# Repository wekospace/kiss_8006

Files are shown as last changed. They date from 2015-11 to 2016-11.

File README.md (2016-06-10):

Repository content
==================

 * datasheets

Datasheets of chips on front panel.

 * front-panel

Schematics and sniffing traces of front panel.

 * pikmm

Schematic and PCB for Raspberry Pi to Kmm front panel interface.

 * pyk8006

Python files (modules, tests, examples) to drive Kmm front panel.

Devices
=======

During development, a K8006 device have been used but this product does exist under various names :
 * KMM3010-SC-B
 * K8006
 * Media Receiver 300
 * X300T
 * KISS KMM
 * Bluewin TV-Box
 * VIP 1216

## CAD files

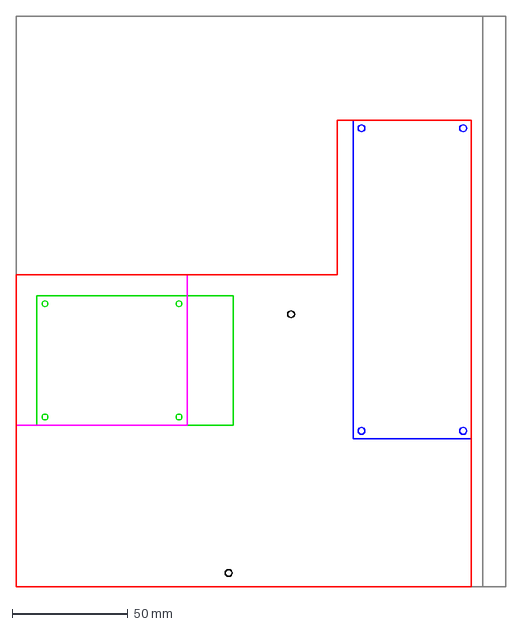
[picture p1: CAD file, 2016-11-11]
case/internal_panel_milling.dxf
212.0 x 247.0 mm

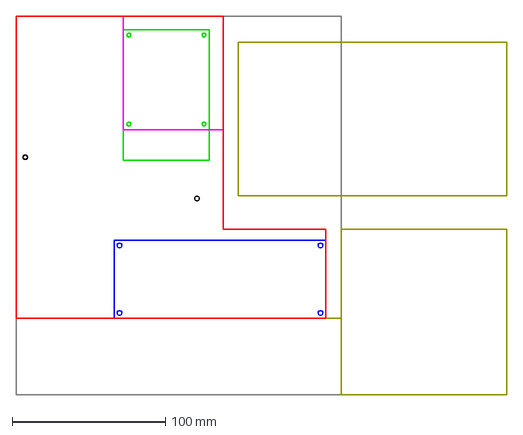
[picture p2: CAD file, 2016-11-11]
case/internal_panel.dxf
320.0 x 247.0 mm

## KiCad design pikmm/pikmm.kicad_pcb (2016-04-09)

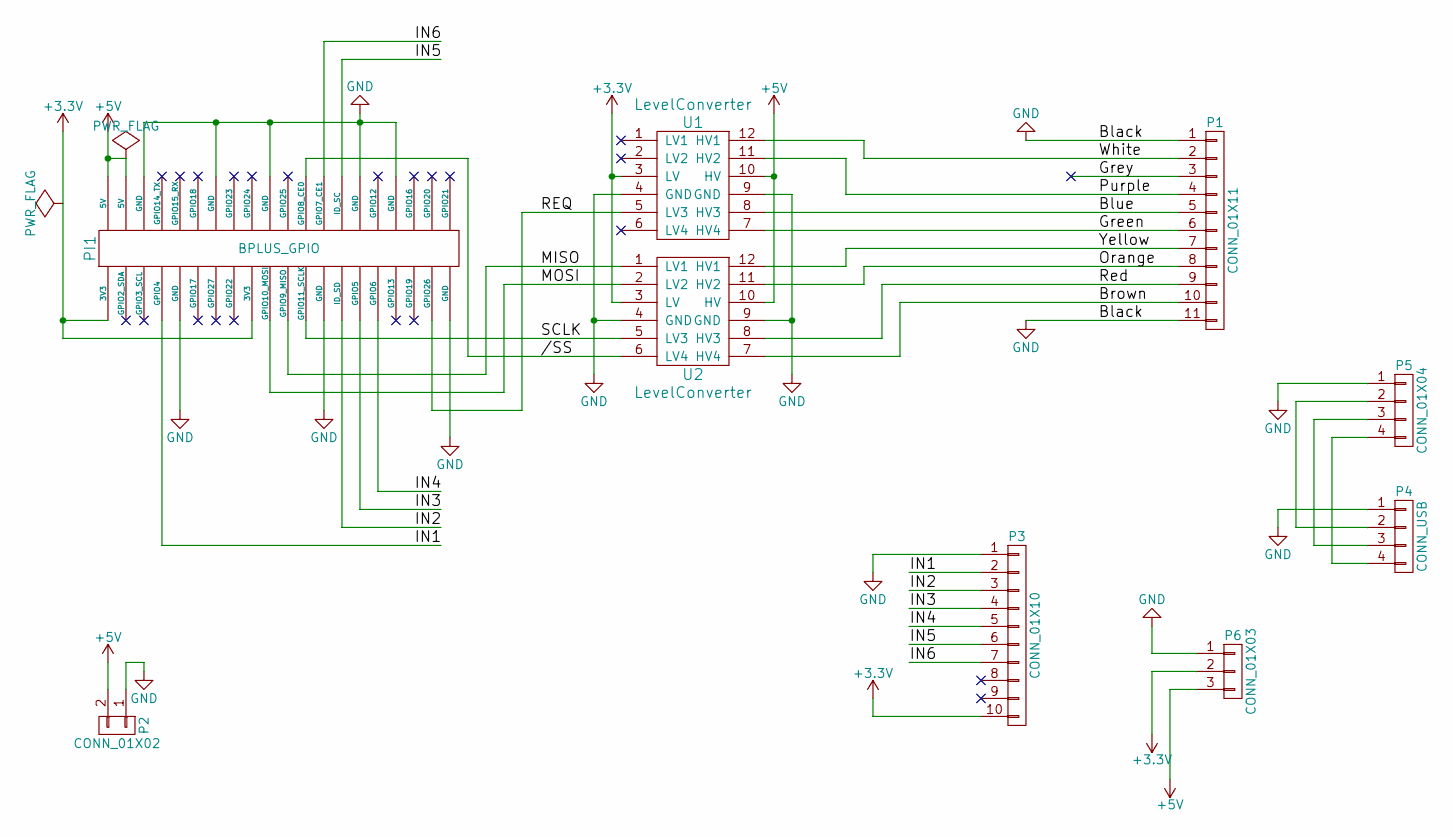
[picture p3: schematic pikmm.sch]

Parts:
P1: CONN_01X11; Molex_PicoBlade_53047-1110
P2: CONN_01X02; Pin_Header_Straight_1x02
P3: CONN_01X10; Pin_Header_Straight_1x10
P4: CONN_USB; Pin_Header_Straight_1x04_Pitch2.00mm
P5: CONN_01X04; Pin_Header_Straight_1x04
P6: CONN_01X03; Pin_Header_Straight_1x03
PI1: BPLUS_GPIO; Pin_Header_Straight_2x20
U1, U2: LevelConverter; DIP12_W5

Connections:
+3V3: P3.10, P6.2, PI1.1 (3V3), PI1.17 (3V3), U1.3 (LV), U2.3 (LV)
+5V: P2.2, P6.3, PI1.2 (5V), PI1.4 (5V), U1.10 (HV), U2.10 (HV)
//SS: PI1.24 (GPIO8_CE0), U2.6 (LV4)
/Blue: P1.5, U1.8 (HV3)
/Brown: P1.10, U2.7 (HV4)
/Green: P1.6, U1.7 (HV4)
/Grey: P1.3
/IN1: P3.2, PI1.7 (GPIO4)
/IN2: P3.3, PI1.27 (ID_SD)
/IN3: P3.4, PI1.29 (GPIO5)
/IN4: P3.5, PI1.31 (GPIO6)
/IN5: P3.6, PI1.28 (ID_SC)
/IN6: P3.7, PI1.26 (GPIO7_CE1)
/MISO: PI1.21 (GPIO9_MISO), U2.1 (LV1)
/MOSI: PI1.19 (GPIO10_MOSI), U2.2 (LV2)
/Orange: P1.8, U2.11 (HV2)
/Purple: P1.4, U1.11 (HV2)
/REQ: PI1.37 (GPIO26), U1.5 (LV3)
/Red: P1.9, U2.8 (HV3)
/SCLK: PI1.23 (GPIO11_SCLK), U2.5 (LV3)
/White: P1.2, U1.12 (HV1)
/Yellow: P1.7, U2.12 (HV1)
GND: P1.1, P1.11, P2.1, P3.1, P4.1, P5.1, P6.1, PI1.6 (GND), PI1.9 (GND), PI1.14 (GND), PI1.20 (GND), PI1.25 (GND), PI1.30 (GND), PI1.34 (GND), PI1.39 (GND), U1.4 (GND), U1.9 (GND), U2.4 (GND), U2.9 (GND)
unnamed: P4.2, P5.2
unnamed: P4.3, P5.3
unnamed: P4.4, P5.4

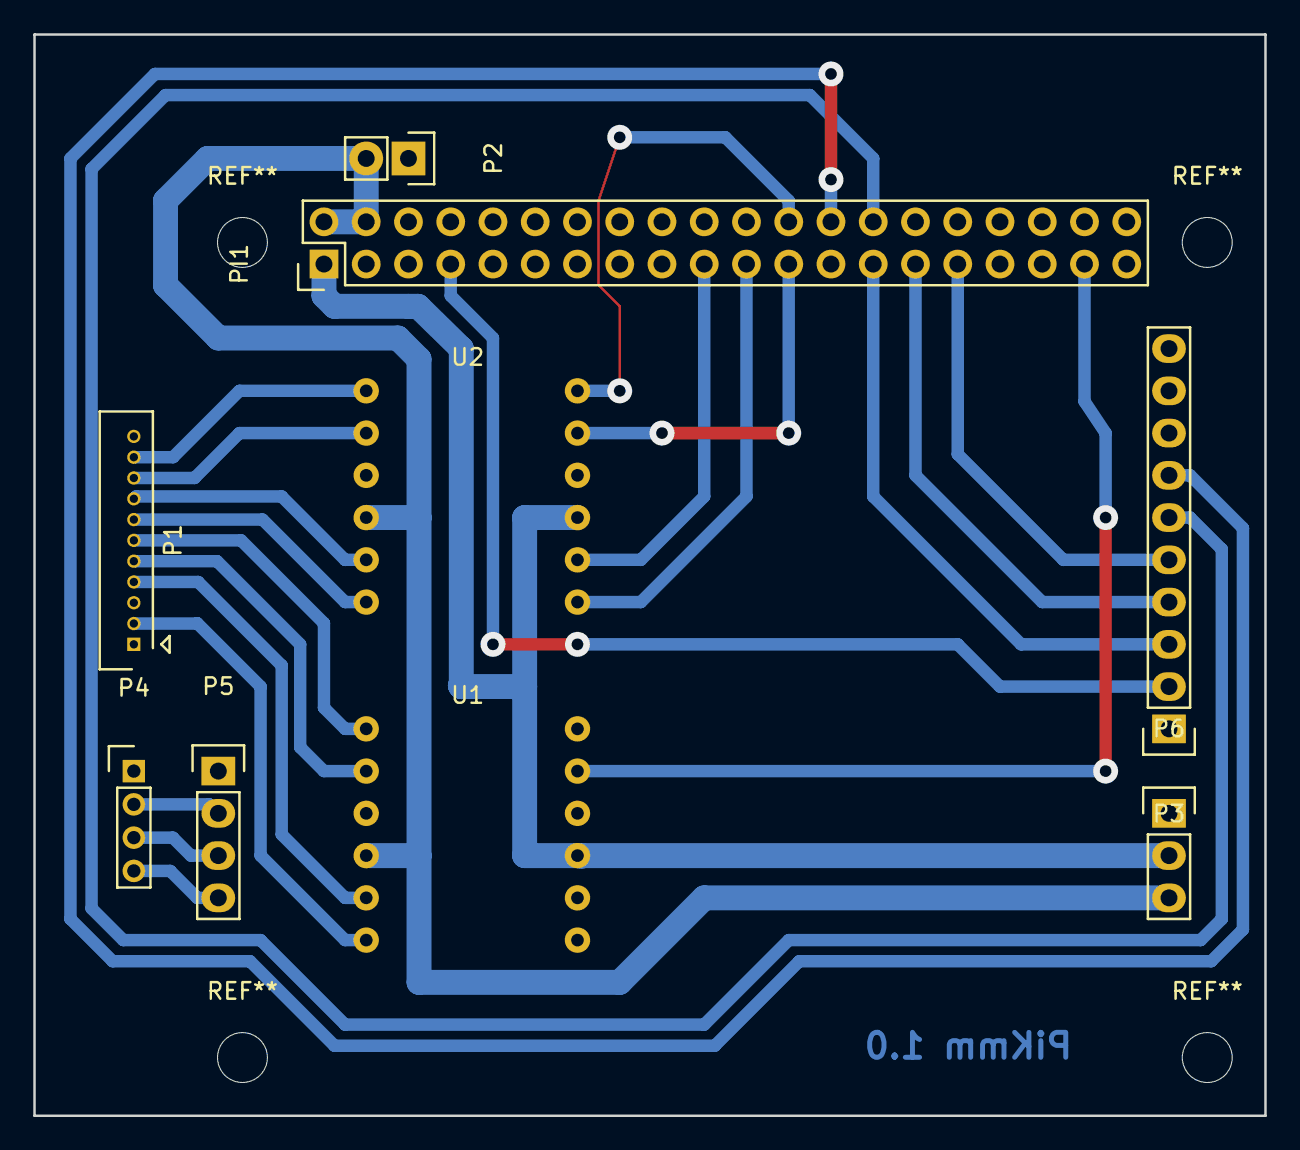
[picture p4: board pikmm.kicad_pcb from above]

Board: 2 copper layers, 74.0 x 65.0 mm, 9 parts (0 on the bottom side), 25 nets.

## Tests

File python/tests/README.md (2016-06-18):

Kmm commands
============

Display
-------

 * Vw => Clear
 * Vc => Clock

Misc
----

 * 'CV' => Get firmware version
 * 'VA' => All, only 'O' works after
 * 'VO' => Blank, only 'A' works after
 * 'VP' => Blank, unable to restart
 * 'CP' => device always reply 0xff after that

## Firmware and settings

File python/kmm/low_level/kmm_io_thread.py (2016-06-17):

#/usr/bin/env python3

import threading
import time
from queue import Queue, Empty
from .kmm_io import KmmIo

class KmmIoThread(threading.Thread):
    def __init__(self, debug):
        self.__debug = debug
        self.__tx = Queue()
        self.__rx = Queue()
        self.__rx_remaining_bytes = 0
        self.__rx_current_buffer = []
        self.__kill = False
        self.__something_to_process = threading.Event()
        self.__waiting_for_rx = threading.Event()
        threading.Thread.__init__(self)
        self.__lv = KmmIo(self.__debug)
        self.__frame_received_callback = None

    def kill(self):
        self.__kill = True
        self.__something_to_process.set()

    def run(self):
        while not self.__kill:
            self.__something_to_process.wait()
            if self.__kill: break
            if not self.__tx.empty():
                self.send(self.__tx.get())
                if not self.__tx.empty():
                  self.__something_to_process.set()
                  continue

            if self.__rx_remaining_bytes > 0:
                self.receive(self.__rx_remaining_bytes)
            elif self.__rx_remaining_bytes == 0 and self.__waiting_for_rx.is_set():
                self.receive(3)
                self.__waiting_for_rx.clear()

            if self.__frame_received_callback != None:
                while not self.__rx.empty():
                    self.__frame_received_callback(self.__rx.get())

            if self.__tx.empty() and self.__rx_remaining_bytes == 0:
                self.__something_to_process.clear()

    def send(self, data):
        rx = self.__lv.send_raw_data(data)
        self.process_received_bytes(rx)

    def receive(self, lenght):
        self.send([0xaa] * lenght)

    def process_rx_buffer(self):
        while len(self.__rx_current_buffer) and self.__rx_current_buffer[0] == 0xaa:
            del self.__rx_current_buffer[0]

        if len(self.__rx_current_buffer):
            if self.__rx_current_buffer[0] == 0x23:
                if len(self.__rx_current_buffer) >= 3:
                    rx_frame_len = (self.__rx_current_buffer[1]-0x30) * 10 + (self.__rx_current_buffer[2]-0x30)
                else:
                    rx_frame_len = 3

                self.__rx_remaining_bytes = rx_frame_len - len(self.__rx_current_buffer)

                if self.__rx_remaining_bytes <= 0 and len(self.__rx_current_buffer):
                    if self.__rx_current_buffer[0:rx_frame_len].count(0x23) != 1:
                        print("Dropping frame : " + str([hex(i) for i in self.__rx_current_buffer]))
                        self.__rx_current_buffer.pop(0)
                        self.drop_junk()
                    else:
                        self.__rx.put(self.__rx_current_buffer[0:rx_frame_len])
                        self.__rx_current_buffer = self.__rx_current_buffer[rx_frame_len:]
                        self.process_rx_buffer()
                        self.__rx_remaining_bytes = 0
            else:
                self.drop_junk()

    def drop_junk(self):
        while len(self.__rx_current_buffer) and (self.__rx_current_buffer[0] != 0x23):
            print("Dropping byte : " + str(hex(self.__rx_current_buffer[0])))
            self.__rx_current_buffer.pop(0)
        if len(self.__rx_current_buffer):
            self.process_rx_buffer()

    def process_received_bytes(self, data):
        self.__rx_current_buffer += data
        self.process_rx_buffer()
        if self.__debug: print("(remaining: " + str(self.__rx_remaining_bytes) + ")")

    def put_tx(self, data):
        if self.__debug: print("+++ " + bytes(data).decode('iso8859-1'))
        self.__tx.put(data)
        self.__something_to_process.set()

    def get_rx(self):
        self.request_reception()
        data = None
        try:
            data = self.__rx.get(timeout=1)
            if self.__debug: print("--- " + str(data))
        except Empty:
            pass
        return data

    def register_frame_received_callback(self, function):
        self.__frame_received_callback = function

    def request_reception(self):
        self.__waiting_for_rx.set()
        self.__something_to_process.set()

    def terminate(self):
        print("I'm HERE")
        while self.is_alive():
            if not self.__something_to_process.is_set(): self.kill()
            self.join(1)

    def wait_until_terminate(self):
        try:
            self.terminate()

        except KeyboardInterrupt:
            print("Ctrl-c pressed ...")
            self.kill()

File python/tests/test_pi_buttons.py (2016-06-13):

#!/usr/bin/env python3

import sys, os
import time

sys.path.append(os.path.join(os.path.realpath(os.path.dirname(__file__)), '../'))

from kmm import *
from kmm.pi import KmmPi

debug=False

fp = KmmPi(debug=debug)

failure_counter = 0

def button_received(button):
    failure_counter = 0
    print(button)
    text = "X" * int(button.duration*7)
    fp.set_text(text)
    fp.check_irq_pin()

fp.register_input_button_callback(button_received)

fp.set_text('Hit a key')

while True:
    time.sleep(1)
    input = fp.read_irq_pin()
    if input != 1:
        failure_counter += 1
        print("Error: IRQ pin value is " + str(input) + ' (' + str(failure_counter) + ')')
        if failure_counter >= 3:
            print('Forcing pin read...')
            fp.check_irq_pin()

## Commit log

2015-11-28 Import front panel schema
    [ci_vfd.kicad_pcb, ci_vfd.sch]
2016-01-17 Import decoded frames and fuzzing results
2016-01-17 Move schematics into dedicated directory
    [ci_vfd.kicad_pcb, ci_vfd.sch]
2016-01-24 Rework python module
    * Add tests
    * Rename functions
    * Use python3
    * Introduice new discovered commands (and features)
    [test_buttons.py, test_display.py]
2016-02-06 Implement an async io thread.
    This commit allow to choose to use a thread to handle IO with Kmm (K8006 front-panel).
    Threading this task permit full-duplex communication: ie. being able to send commands while receiving data.
    Additionnally, this now allow multiple task to queue commands to front panel and to prevent from loosing incomming data
    [test_buttons.py, test_display.py]
2016-02-06 Move LedColor Enum to bottom of file
2016-02-06 Buttons test: only display debug when debug is enabled
2016-02-06 Add KmmPi class to ease setup on Raspberry Pi
2016-02-08 Implement front panel button as KmmInputEvent (pressed, hold and released)
2016-04-08 Schematic: renamed SPI wires
    [ci_vfd.sch]
2016-04-09 PiKmm: initial import
    [pikmm.kicad_pcb, pikmm.sch]
2016-05-08 test_pi_buttons: make it works with PiKmm board
2016-05-08 test_pi_buttons: count detected failures
    Note: it could have false-positive failures due to unsynchronized thread
    [test_pi_buttons.py]
2016-06-10 Tests: add raw Pi IRQ pin test
2016-06-10 pyk8006: set IRQ default pin to PiKmm IRQ pin
2016-06-10 Kodi remote: import kodi client to handle Kmm buttons (local and remote)
2016-06-10 XBMCClient: remove debug-related prints
2016-06-13 Kodiremote: set power LED to green
2016-06-13 KmmIoThread: resync received frame on start byte when relevant
    This commit allow to sync to start of frame when:
    * We receive bytes after start byte (e.g. after a crash)
    * We receive a frame which contains another 0x23, which means we have a bad frame
    [kmm_io_thread.py]
2016-06-17 Kmm: improve print-based debug
2016-06-17 Kmm: only drop frame if current frame is corrupt, not whole buffer
2016-06-17 KmmInputEvent: release last button on error
2016-06-18 Relay: import RelayBoard module
2016-06-18 Move relay test into tests/
2016-06-18 KissMPD: display track duration
2016-06-18 KissMeD: center text when display current mode
2016-06-18 KissMeD: power on when music is started when KissMe is off
2016-06-18 KissMPD: do not print change on stdout
2016-07-04 KissMed: sync multi-thread reading of "mode"
2016-07-04 Relay: handle amplifier relay
2016-07-04 KissMPD: fix text when track have no title or artist
2016-11-11 Update schematics
    [pikmm.sch]
2016-11-11 Import case drawings and milling stand
    [internal_panel.dxf, internal_panel_milling.dxf]
2017-02-25 KissMeD: enable luz power control
2017-03-21 Relay: support "1" as True
2017-03-26 KissMeD: reduce hold time to switch mode
